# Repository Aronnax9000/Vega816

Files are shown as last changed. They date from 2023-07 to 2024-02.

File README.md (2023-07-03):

# Vega816 - Quad 65C816 Computer with Vector Pull rewrite

## Table of Contents

* [Functional Description](#functional-description)
* [CPU Buffer Board](#cpu-buffer-board)
* [DMA Control and Vector Pull Rewrite Shim](#dma-control-and-vector-pull-rewrite-shim)
    * [DMA Control Shim](#dma-control-shim)
    * [Vector Pull Rewrite Shim](#vector-pull-rewrite-shim)
    * [Offset of 7 triggers RESB interrupt handler for W65C816](#offset-of-7-triggers-resb-interrupt-handler-for-w65c816)
    * [Details of Vector Pull address rewriting](#details-of-vector-pull-address-rewriting)
    * [Effect of Vector Pull Rewrite in Emulation (65C02) Mode](#effect-of-vector-pull-rewrite-in-emulation-65c02-mode)
* [IRQ Dispatcher](#irq-dispatcher)
    * [IRQ Priority 7 to NMI Option](#irq-priority-7-to-nmi-option)
* [DMA Controller](#dma-controller)
    * [DMA Channels and Address Interleaving](#dma-channels-and-address-interleaving)
    * [How the DMA Controller routes requests](#how-the-dma-controller-routes-requests)
    * [DMA Request timing](#dma-request-timing)
* [Programmable Interrupt Controller (PIC)](#programmable-interrupt-controller-pic)
    * [2 Device PIC](#2-device-pic)
    * [Quad 2-Device PIC](#quad-2-device-pic)
* [16 MB Memory Decoder and Bus](#16-mb-memory-decoder-and-bus)
* [4 MB RAM + 32 K EEPROM Module](#4-mb-ram-32-k-eeprom-module)
* [Quad 64B I/O Bus](#quad-64b-i-o-bus)
* [Expansion Port to Single Device Ports](#expansion-port-to-single-device)
* [Single Device Port Breakouts](#single-device-port-breakouts)
* [Devices](#devices)
    * [W65C22 VIA Port](#w65c22-via-port)
    * [W65C51N ACIA (RS-232)](#w65c51n-acia-rs-232)
    * [8580/6581 SID](#8580-6581-sid)

* [VIA Port Devices](#via-port-devices)
    * [2x16 Character Display and front panel switches](#2x16-character-display-and-front-panel-switches)
    * [System Controller / SPI Controller](#system-controller-spi-controller)
    * [Ben Eater PS/2 Interface](#ben-eater-ps-2-interface)
    * [Commodore 64 CIA (VIA) #1](#commodore-64-cia-via-1)

## Functional Description
Vega 816 Block Diagram

The Vega816 is a modular architecture for implementing symmetrical multiprocessing (SMP) with the Western Design Center W65C816 Microprocessor (aka 65816). The project takes as its starting point the 65816 breakout board designed by Adrien Kohlbecker, documented at [the project's GitHub page](https://github.com/adrienkohlbecker/BB816) as well as [Adrien's YouTube series](https://www.youtube.com/playlist?list=PLdGm_pyUmoII9D16mzw-XsJjHKi3f1kqT).

Support is provided for up to four bus mastering devices (four CPUs, or three CPUs and a video card) accessing up to four DMA channels. Each DMA channel has full 24 bit addressing and therefore 16 MB of address space.

Through the use of software programmable banking registers, all four CPUs share access to all four 16 MB DMA channels, for a total of 64 MB of shared memory.

The architecture can be extended in a star pattern to form massively parallel networks, by connecting one DMA channel from one node as an input CPU channel on a higher-order node in the hierarchy.

## Modular Design

The design is implemented as a series of pluggable printed circuit modules, each introducing
one or two important layers of functionality to the basic system. Omitting a module should not interfere with the functioning of the remaining modules, except to omit the specific functionality it provides. Default settings in hardware and software exist to bypass any  undesired features. Interfaces between boards are designed as implementation neutral. For example, the CPU Buffer board takes only four inputs, each of which switches on one DMA channel. A DMA controller must be provided to make effective use of the board, but the choice of DMA controller is not forced, only the format of its required output.

## CPU Buffer Board

The CPU Buffer board provides two straight-wired connectors for the BB816 CPU breakout board, called "the CPU end", and buffers communications between the two of them and dual output connectors with the same pinout, called "the DMA end".

The extra straight wired connectors are included for ease of stacking the boards, both on the CPU end, and on the DMA end, in a multiplexed configuration, to implement shared memory multiprocessing. 

The circuit uses a 74AHCT245 octal bus transceiver for bi-directional communication for the 8 data lines, and seven 74HC541 octal buffers for the remaining signals provided by the BB816 CPU breakout board, including VPA and VDA. One of the buffers is allocated to CPU inputs (NMIB, IRQB, ABORTB, RDY_IN, etc), buffering signals from the DMA end. The remaining 74HC541s buffer lines from the CPU end onto the DMA end.

The bus transceiver and buffers' output enable lines are tied together and provided as an active low input called DMAB, so that a single signal suffices to turn communication on and off. A 1K pulldown resistor ensures that the board is active unless DMAB is raised high by external hardware.

CPU Buffer Board

## DMA Control and Vector Pull Rewrite Shim

If we assign each DMA channel its own address space, we can use address decoding in order to select which DMA channel is to be accessed by a particular CPU. In order to do that, we need to intercept the address lines from the CPU, pass decoding information to the DMA controller, and potentially rewrite the address being asserted by the CPU, before granting the CPU buffer access to the correct DMA channel.

The W65C816's VPB (Vector Pull) line also allows rewriting of the address asserted by the CPU when it is pulling an interrupt vector. It is convenient to provide hardware to intercept and rewrite the vector pull address as part of the same adapter.

Together, the DMA Control Shim and the Vector Pull Rewrite Shim provide facilities for DMA control and Vector Pull Rewrite to be performed by external hardware. 
CPU Shim

### DMA Control Shim

The DMA Control shim provides movable jumpers for each of the bits A16-A23. Any of the bits may be selected as DMA_REQ. Once the jumper has been set to select one of those lines, it is connected as the DMA_REQ output, and disconnected from output to the DMA end, and is in fact pulled low on the DMA end (10K resistor), in order to map the request into a lower part of the DMA channel's address space.

The jumper offers the user a choice of granularity of DMA channel address mapping, in multiple of 2 increments from 64K (single bank, the minimum granularity) to 4M maximum. This allows for the address space to be contiguous across all DMA channels, depending on installed memory sizes. Ordinarily, this jumper should be set to the size of the maximum address space serviced by the hardware on either DMA channel, e.g. the total installed memory on that channel, or half the total memory across the two channels.

### Vector Pull Rewrite Shim

The Vector Pull Rewrite shim allows the IRQ Dispatcher to alter the fetch address of the processor when it is fetching an IRQ vector. A three bit number between 0-7 is added to the least significant bits (but one) of the fetch address, A1-A3, with carry into A4.

The VPB line is brought active low by the 65C816 during the fetch of any interrupt vector, not just IRQ. However, the standard IRQ vector's address has a unique bit pattern which makes it easy to autodetect, so that the shim will only request a vector pull offset when fetching the IRQ vector, and not for any other kind of interrupt.

When VPB is active (low) and A1-A3 are all high, indicating that an interrupt vector is being fetched by the processor, the shim requests a vector pull offset from the IRQ Dispatcher by asserting VP_REQ (positive logic). Pulldown resistors keep the offset equal to zero when Y0-Y2 are not connected (no IRQ Dispatcher) or in a high impedance state. 

A 74HC283 adder is used to add an offset to A1-A4 equal to the three bit number provided as input to the shim from the IRQ Dispatcher, on pins Y0-Y2. This has the effect of altering the fetch of the IRQ vector at $FFEE to a fetch of a vector at one of the following eight addresses: 
```
$00FFEE IRQ 0 
$00FFF0 IRQ 1 
$00FFF2 IRQ 2 
$00FFF4 IRQ 3 
$00FFF6 IRQ 4 
$00FFF8 IRQ 5 
$00FFFA IRQ 6 
$00FFFC RESET 
```
Y0-Y2 are pulled low by 10K resistors, for cases in which no Vector Pull controller is connected. Bypass jumpers are also provided for A1-A4, in case the 74HC283 adder and supporting logic are not installed.

The connector for the external Vector Pull Rewrite controller provides the E signal from the CPU, so that the Vector Pull Rewrite controller can know which scheme of vector pull (W65C02, W65C816) is being used.

#### Exposure of NMI and IRQ

The Vector Pull Rewrite shim exposes both IRQ and NMI to the IRQ Dispatcher. 

If the IRQ Dispatcher is not installed, a jumper on the Quad 64 IO Bus (IRQ Dispatch Bypass) should be installed to route IRQs to the common IRQ signal on the CPU via the CPU Buffer's DMA Channel connector.

When the IRQ Dispatcher is installed, the dispatcher takes responsibility for issuing IRQ to the CPU, via the Vector Pull Rewrite shim.

The exposure of NMI allows a device to raise an  IRQs at a selected IRQ priority level (say, IRQ 7) and instead trigger NMI, as the Commodore 64 RESTORE key did. The assertion of NMI is left under the control of the IRQ Dispatcher.

In scenarios where the IRQ Dispatcher is not installed, a jumper on the Quad 64B IO Bus (NMI Dispatch Bypass) can be used to direct IRQA7, IRQB7, both, or neither, to NMI.

#### Offset of 7 triggers RESB interrupt handler for W65C816

Note that, when the 65816 is running in native mode, if an IRQ priority of 7 (0x111) is asserted on Y0-Y2, the vector offset will result in the RESET vector being pulled. Since no actual hardware reset has occurred, if the reset handler relies on a hardware reset having taken place, unpredictable state may occur. It is generally advised to avoid the use of IRQ priority 7 when the CPU is in native mode. Alternatively, IRQ priority 7 may be rerouted to NMI, either through the IRQ Dispatcher, or a jumper on the Quad 64B IO Bus.

#### Details of Vector Pull address rewriting
The W65C816 datasheet gives this table of interrupt vectors which lie between $00FFE4 and $00FFFC
```
Address Function Last Octet (binary)
$00FFE4 COP      0x1110 0100
$00FFE6 BRK      0x1110 0110
$00FFE8 ABORT    0x1110 1000
$00FFEA NMI      0x1110 1010
$00FFEE IRQ      0x1110 1110
$00FFFC RESET    0x1111 1100
```
The datasheet also specifies that when the 65C816 is addressing an interrupt vector, it pulls its VPB line low. This is to allow the system to override the fetched interrupt vector with any other. 

VPB is pulled low for any interrupt vector fetch, not just IRQ, but the present design purposefully limits Vector Pull rewriting to only those cases when IRQ is the vector being fetched.

Note that the last nybble of each of the standard interrupt vectors is unique, which aids in designing a hook for any one of them (the same is true for 6502 Emulation mode, see below). A test of these four bits suffices to uniquely identify the vector being pulled. In particular, both bytes of the two-byte IRQ vector ($FFEE and $FFEF) are the only two bytes in this table with $E or $F (0x1110, 0x1111) as the last nybble of address, i.e., A1-A3 high.

Note also the gap of 12 bytes between the IRQ vector and the RESET vector. Since each vector occupies two bytes, this gap provides sufficient space to specify six (6) additional vectors. 

```
$00FFE4 COP	
$00FFE6 BRK
$00FFE8 ABORT 
$00FFEA NMI 
$00FFEE IRQ 0 
$00FFF0 IRQ 1 
$00FFF2 IRQ 2 
$00FFF4 IRQ 3 
$00FFF6 IRQ 4 
$00FFF8 IRQ 5 
$00FFFA IRQ 6 
$00FFFC RESET 
```
If an offset 0-6 is added to A1-A3, (leaving A0 as found), then the vector fetched will be as shown above, going forward from IRQ0.

#### Effect of Vector Pull Rewrite in Emulation (65C02) Mode
The 6502's IRQ vector, like its 65816 counterpart, has 0x111x in the last nybble, so it is detected by the Vector Pull Rewrite Shim. 
```
$FFFA NMI
$FFFC RESB
$FFFE BRK/IRQ 
```
Unlike the 65816's IRQ vector, the 6502 IRQ vector occurs at the very top of its page, so additions of 1-7 to the bits may force A4 to overflow to 0 (no carry). In particular, $FFFE + $02 = $FFE0, etc. This means the augmented
IRQ vector map for the 6502 looks like this:

```
$FFE0 BRK/IRQ 1
$FFE2 BRK/IRQ 2
$FFE4 BRK/IRQ 3
$FFE6 BRK/IRQ 4
$FFE8 BRK/IRQ 5
$FFEA BRK/IRQ 6
$FFEC BRK/IRQ 7
...
$FFFA NMI
$FFFC RESB
$FFFE BRK/IRQ 0
```
## IRQ Dispatcher

Devices mapped within the physical address space of either DMA channel may raise interrupt requests against either CPU. For each CPU, an 8-to-3 priority encoders is used to prioritize eight different levels of IRQ, from 0-7, with lower values meaning higher priority.

The priority is encoded as a three bit offset and offered to the Vector Pull Rewrite shim, on pins Y0-Y2, where it is used to offset the fetch addresses of the CPU's next two-byte IRQ vector pull. 

IRQs received from DMA channel 0 and intended for CPU A or CPU B will be routed to those CPUs. 

For IRQs received from DMA channel 1, the situation is reversed: IRQs which DMA channel 1 intended for CPU A will be routed to CPU B, and vice versa. This crossover in routing means that the CPU target values in the system's PIC controllers always refer to the same physical CPU. I.e., CPU A is always target 0, and CPU B is always target 1, no matter on which DMA channel a PIC is installed. The crossover is reflected in the connector placement on the IRQ Dispatcher: no crossover cable is needed.

### IRQ Priority 7 to NMI Option

The combined IRQ signals are diode-NANDed together to drive IRQ on the CPU through the Vector Pull Rewrite shim. IRQ priorities 0-6 are NANDed together first, with priority 7 NANDed to the result unless jumper IRQA7 or IRQB7 are set to direct priority 7 to NMI to CPU A or CPU B.

Rerouting IRQ Priority 7 to NMI is offered elsewhere in the design, as a jumper on the Quad 64B IO Bus, for cases where no IRQ Dispatcher and/or Vector Pull Rewrite shim is installed. See the documentation on the Quad 64B IO Bus.

IRQ Dispatch

## DMA Controller

The DMA Controller is intended to control the multiplexing of one or two CPUs (called CPU A and CPU B) onto one or two communication channels (called DMA 0 and DMA 1). The two channels are cross-mapped in address space from the point of view of opposite processors, depending on a selected granularity. For example, if 64 KB (single bank) granularity is selected, when CPU A requests Bank 0, the DMA controller will connect it to DMA channel 0, whereas if CPU A requests Bank 1, the controller will connect it to DMA channel 1. The situation is reversed for CPU B. The controller will direct its requests for Bank 0 to DMA channel 1, and requests for Bank 1 to DMA channel 0.

This permits each CPU to have its Bank 0 lie within the address space of a separate physical DMA channel, so that accesses by each CPU to its own Bank 0 will not normally interfere with the opposite CPU's requests for its own Bank 0.

The effect for higher memory is that each CPU's odd numbered banks are the other CPU's even numbered banks, interleaved to the top of physical memory.

The granularity of the interleaving is specified by a jumper on the DMA Controller Shim, and provided to the DMA controller as the signal DMA_REQ. Additionally, the following CPU signals are utilized in implementing DMA:
```
RDY_IN
ABORTB
VA
```
Since the DMA controller will dispatch requests from up to two CPUs, CPU A and CPU B, the signals are distinguished within the controller with these designations:

Inputs
```
DMA_REQB_A DMA_REQB_A
RDY_IN_A  RDY_IN_B
ABORTB_A  ABORTB_B
VA_A      VA_B
```
Since the DMA channels are cross-mapped in address range between the two CPUs, so that each CPU's DMA 0 corresponds to the lower part of its address space with respect to DMA 1, the outputs are:
```
DMA_0_A  = DMA_1_B
DMA_1_A  = DMA_0_B
```
This cross mapping, which takes place in the connector wiring of the DMA Controller board, means that two identically configured units may be connected as CPU A or CPU B, provided that their DMA buffer modules are connected with the sense of DMA 0 and DMA 1 reversed.

The "home" channel for a CPU is the DMA channel containing that CPU's Bank Zero.

Here are the possible scenarios for DMA arbitration:

1. Both CPUs are asserting valid address, each against their own home DMA channels. CPU A is using DMA 0, and CPU B is using DMA 1.
2. Both CPUs are asserting valid address, against the opposite CPU's home DMA channel. CPU A is asserting against DMA 1, and CPU B is asserting against DMA 0.
3. Both CPUs are asserting valid address against the same DMA channel. CPU A is asserting against DMA 0, and so is CPU B.
4. Both CPUs are asserting valid address against the same DMA channel. CPU A is asserting against DMA 1, and so is CPU B.

The DMA controller monitors the VA (Valid Address) from one or two CPUs, as well as an additional input, DMA_REQB. If one CPU asserts DMA_REQB, the controller checks the VA line from the opposite CPU. If it is not active, the controller asserts DMA
DMA Controller

### DMA Channels and Address Interleaving

When no request granularity is set for a CPU on the DMA Control Shim, all DMA requests take place against DMA 0.

If only the primary granularity is set, DMA requests will take place against DMA 0 and DMA 2.
If only the secondary granularity is set, DMA requests will take place against DMA 0 and DMA 1.

If both granularities are set, DMA requests will take place against DMA 0-3. The maximum granularity for four channel DMA is 4 MB, with primary set at 8 MB and secondary set at 4MB. (0x1100 0000). In that case,

```
Requests for the range 
(0x00?? ????) go to DMA channel 0
(0x01?? ????) go to DMA channel 1
(0x10?? ????) go to DMA channel 2
(0x11?? ????) go to DMA channel 3
```

The DMA controller maps requests so that each CPU sees a different DMA channel as its channel 0, with subsequent channels in order. The next CPU's channel 0 is the present CPU's channel 1, and channel 0 for the next CPU after that is channel 2. The order wraps to form a closed ring.

```
           Requested           Physical
CPU   A    B      C      D
      0    1      2      3      DMA 0
      1    2      3      0      DMA 1
      2    3      0      1      DMA 2
      3    0      1      2      DMA 3
```

From the chart it can be seen that the channel that CPU A sees as DMA 0 is seen by CPU B as DMA channel 3, etc.

DMA request granularity may or may not match the largest installed address size.

Since the address bits used to select the DMA channels are suppressed in the address presented to the destination channel, if a CPU's request granularity is set to a smaller value than the installed memory size on any given DMA channel, then a range of that memory will not be accessible to that CPU.

CPU A has primary DMA on 1M, and secondary DMA set to 512K. 
CPU A issues requests against Banks 0 to 7.

What DMA channels are addressed?

```
0x000 Bank 0x000 0 on DMA 0
0x001 Bank 0x000 0 on DMA 1
0x010 Bank 0x000 0 on DMA 2
0x011 Bank 0x000 0 on DMA 3
0x100 Bank 0x100 4 on DMA 0
0x101 Bank 0x100 4 on DMA 1
0x110 Bank 0x100 4 on DMA 2
0x111 Bank 0x100 4 on DMA 3
```

### How the DMA Controller routes requests

Each request enters the DMA controller as a two bit code, representing the two address lines selected by jumper settings on the DMA Control Shim. These two bits are augmented with a third bit, a CPU Priority bit supplied for that CPU. The CPU Priority bit is active low, and pulled high. 

The three bit request is decoded into a one in eight choice, each representing a request for one of four DMA channels, with and without priority. The eight decoded request lines are then routed, together with the decoded request lines from the other CPUs, into priority encoders, one for each of the four DMA channels. The eight request lines entering each DMA channel's priority encoder are wired so that the four priority requests occur with highest priority, followed by the four no-priority request lines. Among the two sets of priority requests, Each DMA channel gives greatest priority to a particular CPU, followed by the others in ring order.

```
DMA Channel   Order
     0        ADCB                  
     1        BADC            
     2        CBAD
     3        DCBA            
```

When more than one CPU requests the same DMA channel, the losing CPU(s) must be informed, since they will not have access to the DMA channel for the duration of the current clock cycle. 

The W65C816 provides two mechanisms for this, the READY signal, and the ABORTB interrupt signal. The READY signal pauses the processor, if pulled low. Releasing the low condition, allowing READY to return high, will cause the CPU to resume processing on the rising edge of the next clock cycle.

Adrien Kohlbecker's BB816 CPU breakout provides the input to the READY signal as RDY_IN. This signal is that which is used by the DMA Controller to pause the CPU.

If the losing CPU is losing access to its Bank Zero channel (due to the winning CPU having priority bit active), the losing CPU is paused, by pulling RDY_IN low. 

Any other losing CPU is informed by pulling the losing CPU's ABORTB low, triggering the losing CPU's ABORT Interrupt handler. In most cases, the handler will simply return control to the interrupted process so that another attempt at access to the DMA channel can be made on the next clock cycle.

### DMA Request timing

CPU to DMA routing must be complete, with time to spare for the devices on the DMA channel to decode incoming address, before the routing is latched in on the falling edge of the clock. Now latched, the CPU to DMA channel routing persists through the remainder of the clock cycle, until unlatched at the rising edge of the clock at the beginning of the next cycle, so that arbitration may begin again.

## Quad 64B I/O Bus
The I/O bus board decodes a selected page (256 bytes) of address space for device I/O, together with a corresponding range in the the page immediately above it, for use by I/O devices.
3
Jumpers set the base I/O address space on any even-numbered page boundary in Bank Zero. The page of address space immediately above the base I/O page is reserved for configuring the programmable interrupt controller (PIC). For example, if the bus is set so that its base address is $0200, then page $0300 is reserved for use by the PIC.

The odd numbered page immediately above the base page is used by the programmable interrupt controller to store IRQ priority and CPU target information for use in forwarding interrupt requests issued by devices under PIC control.

In order to avoid the default page zero and stack areas at $0000 and $01000, it is advisable to avoid setting the I/O base address to page $00, leaving 63 possible pages between $0200-$7E00.

Four I/O expansion ports are provided, each spanning 64 bytes of the assigned I/O page. Each port is provided with a one-in-four chip select signal based on further decoding of the address, into 16 byte ranges areas. 
Standard connections are provided for adding a CS Decode module which can perform finer and/or coarser grained address decoding into 64, 32, and 8 byte I/O address ranges.

The 16 byte range chip select signals are raised high for both the I/O page within that 16 byte range, as well as for that range in the page immediately above it. E.g., if a device is mapped to $0210-$021F, then the chip select for that device is also active for the range $0310-$031F. This allows access to latches used to store programmable interrupt configuration, and potentially other metadata used in controlling the device.

The 16 IRQ output lines from each expansion port (8 priorities destined for one of up to two CPUs) are multiplexed via diode logic for dispatch by the IRQ Dispatch board.

Quad 64-byte Expansion Bus and IRQ Multiplexer

## Programmable Interrupt Controller (PIC)

### 2 Device PIC
The programmable interrupt controller accepts active low IRQ inputs from up to two sources. For each source, the PIC generates an interrupt signal at one of eight pre-selectable priorities (0-7), and directs the interrupt to a preselected one of two target CPUs. The PIC uses diode logic so that interrupts generated by multiple PICs may be placed on the same IRQ bus. 

The IRQ bus terminates at the IRQ Dispatcher, where 10K pull-up resistors ensure that lines on the IRQ bus are held high, unless pulled low by an interrupt signal originating at a PIC.

2 IRQ PIC

### Quad 2-Device PIC
A 64-byte expansion slot may include a programmable interrupt controller. The PIC subdivides the 64 byte address range into eight 8-byte device I/O spaces, two for each of the 16-byte address ranges decoded by the expansion bus controller and supplied to the PIC as chip select lines. 

Both IRQ priority (0-7) and CPU destination (CPU A or CPU B) can be programmed for each of up to eight devices, by writing to latches which shadow the device I/O space in the next higher page of address space. Four octal latches, at address offsets +$100, +$104, +$108 and +$10C offsets from the corresponding 16 byte I/O address ranges are provided. Each octal latch stores programmable interrupt information for up to two 8 byte devices: the low nybble for an eight byte device at offset +$00 from the base I/O address, and the high nybble for an eight byte device at offset $08 from the base I/O address. The low bit of the nybble determines the target CPU. The high three bits specify the priority from 0-7.
PIC (Programmable Interrupt Controller

## 16 MB Memory Decoder and Bus

16 MB Memory Decoder and Bus

## 4 MB RAM + 32 K EEPROM Module

4 MB RAM + 32 K EEPROM Module

## Expansion Port to Single Device

The 64-byte expansion slots provided by the Expansion Bus may be broken out into individual device I/O ports spanning 64, 32, 16, or 8 bytes of address space. The four 16-byte chip select lines are further decoded by the programmable interrupt controller down to two 8-byte chip select lines per 16 byte range.

These sample breakouts show a complete breakout of one port into 1x64, 2x32, 4x16 and 8x8 byte device ports. Also shown is a reduction of this most general breakout into a sample breakout capable of supporting 3 VIAs and 2 ACIAs.

Expansion Port to 64, 32, 16, 8 bit device ports

## Single Device Port Breakouts
A single 64, 32, or 16 byte device port may be further adapted to serve multiple devices of smaller address range. This approach introduces an extra address decoding delay compared with the above approach of adapting expansion bus directly.

Device Port External Breakouts

## Devices

### W65C22 VIA Port

This device presents the 20 outward facing lines of a VIA port, plus power and ground.

VIA Port

### W65C51N ACIA (RS-232)

This device supplies an RS-232 serial port.

ACIA Port

## VIA Port Devices

### 2x16 Character Display and front panel switches

2x16 Character Display

### System Controller / SPI Controller

The System Controller / SPI Controller is a VIA port device providing software control over system hardware.

Port A controls clock speed, CPU B RDY_IN and DMA priority control, and EEPROM banking on each of the DMA channels.

On system reset:

* CPU B is paused
* both CPUs are set to slow clock
* CPU B DMA Priority is turned off. CPU B will not be able to unilaterally deassert RDY_IN on CPU A for DMA operations.
* EEPROM on DMA 0 is set to read, with writes to the ROM area taking place against underlying RAM.
* EEPROM on DMA 1 is set to read, with writes to the ROM area taking place against underlying RAM.

A typical startup sequence would consist of these steps:

* CPU A copies EEPROM on DMA 0 to underlying RAM.
* CPU A copies EEPROM on DMA 1 to underlying RAM, or otherwise populates RAM underlying the DMA 1 ROM area.
* CPU A banks out EEPROMs for both read and write
* CPU A sets high clock speed for CPU A and CPU B
* If desired, CPU B is given DMA priority (e. g. for video processing).
* CPU A asserts RDY_IN on CPU B, permitting CPU B to start processing with CPU B's RESET vector.

Port B provides SPI communication, with SCK, MISO, MOSI lines, and three chip select lines, which in turn drive a 74AHC138 3-to-8 controller to select one of eight external SPI devices. PB6 and PB7 are reserved for pulse generation and pulse counting purposes (see W65C22 datasheet).

System and SPI Controller

### Ben Eater PS/2 Interface

Ben Eater PS/2 Interface

### Commodore 64 CIA (VIA) #1

Commodore 64 CIA (VIA) #1

### 8580/6581 SID

8580 or 6581 SID

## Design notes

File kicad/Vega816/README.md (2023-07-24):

# Vega816 - DMA Arbitration and VPB Rewrite for BB816 Breakout

The Vega816 is a SMP (Symmetrical Multiprocessing) architecture for Adrien Kohlbecker's 65816
Breakout Board, part of Adrien's astonishingly meticulous BB816 project. 
Hereinafter, unless otherwise specified, "CPU" refers to the W65C816S as wrapped 
in Adrien's W65C816 Breakout Board, or other device (e.g. GPU) made to expose relevant features of
the same interface. The current schematics reference BB816 Breakout Board Revision A.27.

The Vega816 allows up to four CPUs or other bus mastering devices shared access 
to up to four DMA channels, designated DMA0 to DMA3. Each DMA channel provides a
full 16 MB of address space. To ensure that each CPU has its own independent Bank Zero
at startup, each CPU has an independent physical DMA channel as its own "home" DMA0,
with the remaining channels numbered in circular fashion. 

As an independent feature, Vector Pull Rewrite is implemented, providing up to 8 separate
possible IRQ vectors, IRQB0-IRQB7. When an IRQ is asserted on one of the eight provided IRQ inputs,
a priority encoder calculates a three bit offset, and adds double this number to the address
being fetched by the CPU when an IRQ Vector Pull is detected (vectors occupy two bytes, accounting
for the doubled offset used to fetch both bytes). 

The Vector Pull Rewrite Feature works in either Emulation or Native mode.

## Implementation Details

Each CPU is mounted in a "CPU Shim", with identical input and output connectors each wired to 
the BB816 Breakout Board standard. The CPU Shim provides hardware hooks for connecting a DMA Controller,
and eight separate IRQ inputs used by the IRQ Priority Vector Pull Rewrite feature, which is 
also provided by the CPU Shim. 

Both the DMA Control section and the Vector Pull Rewrite section
may alter input and output between the CPU and the bus. For example, since the DMA process 
may result in a change to A23-A22, the BANK0B line is recalculated, so that the value on the bus
reflects whether Bank Zero is being requested on the destination DMA channel.

The CPU Shim is mounted on the CPU Buffer Board, which buffers access between the CPU and one out of 
up to four physical DMA channels. Each DMA channel on the buffer board replicates the full 
BB816 Breakout Board interface. Any hardware built to accept a BB816 Breakout Board 
as its CPU can be attached to a DMA channel without modification. 

The CPU Buffer takes a 1-of-4 input which switches on one of the four physical DMA channel
buffers. 

When not enabled, each DMA channel is in a high impedance state. This allows the buffer 
boards to be "stacked": DMA channels from separate boards may be physically connected 
together so that multiple CPUs share multiple DMA channels. If very long/tall pin headers
are installed, the boards may be physically stacked one atop another. 

When DMA requests are not enabled for a particular CPU, it will always request DMA0. 
When DMA requests are enabled for a particular CPU, the lines A23 and A22 are
decoded as the requested DMA channel and passed to the DMA Controller, along with a priority bit
setting.  

A four channel DMA Controller accepts requests from up to four CPUs, and uses priority decoding
logic to assign CPUs to DMA channels on each clock cycle. A CPU which does not
"win" access to its requested DMA channel is "paused" for one cycle. A pulse is
applied to that CPU's READY_IN, causing it to pause until the falling edge of the next
clock cycle.

Under ordinary circumstances, a CPU always wins priority access to the DMA 
channel that it has designated DMA0. If another CPU (GPU) needs access to
another CPU's DMA0, it will be paused, unless it also has asserted a "Priority Bit"
to the DMA Controller. In that case, the CPU whose home DMA0 channel has been
requested by the visiting CPU will be paused, instead, and the visiting
CPU will be granted access. This feature supports real time applications 
such as VIC-II and World's Worst Video Card style DMA.

Each CPU is mounted on a CPU Shim, consisting of a DMA Shim and Vector Pull Rewrite Shim.

The DMA Control Shim monitors CPU address lines and, when the CPU is in Native mode,
issues DMA requests to the DMA Controller. The DMA Controller performs bus arbitration among
the installed CPUs. If a CPU wins access to a DMA channel for a given clock cycle,
its DMA Control Shim receives the go-ahead from the DMA Controller, and switches on the
correct channel on the CPU's CPU Buffer. Otherwise, the DMA Control Shim pauses its
CPU, by asserting RDY_IN low.

The Vector Pull Rewrite Shim allows eight levels of IRQ priority from 0-7. Priority 7 may be 
rerouted to perform NMI instead. When one of the IRQ inputs not designated for NMI
is pulled low, the VPB Rewrite Shim pulls IRQ low on the CPU, and
monitors VPB and A0-A8 to detect when the interrupt vector is pulled by the CPU in response.
The VPB Rewrite Shim then modifies the fetched vector's address by adding an even number
offset between 0 and 14 to the vector fetch address. The number is calculated as twice the
highest IRQ Priority of the current asserted IRQs.
    
## Functional Description
Vega 816 Block Diagram

The Vega816 is a modular architecture for implementing symmetrical multiprocessing (SMP) with the Western Design Center W65C816 Microprocessor (aka 65816). The project takes as its starting point the 65816 breakout board designed by Adrien Kohlbecker, documented at [the project's GitHub page](https://github.com/adrienkohlbecker/BB816) as well as [Adrien's YouTube series](https://www.youtube.com/playlist?list=PLdGm_pyUmoII9D16mzw-XsJjHKi3f1kqT).

Support is provided for up to four bus mastering devices (four CPUs, or three CPUs and a video card) accessing up to four DMA channels. Each DMA channel has full 24 bit addressing and therefore 16 MB of address space.

Through the use of software programmable banking registers, all four CPUs share access to all four 16 MB DMA channels, for a total of 64 MB of shared memory.

The architecture can be extended in a star pattern to form massively parallel networks, by connecting one DMA channel from one node as an input CPU channel on a higher-order node in the hierarchy.

The DMA Control shim provides movable jumpers for each of the bits A16-A23. Any of the bits may be selected as DMA_REQ. Once the jumper has been set to select one of those lines, it is connected as the DMA_REQ output, and disconnected from output to the DMA end, and is in fact pulled low on the DMA end (10K resistor), in order to map the request into a lower part of the DMA channel's address space.

The jumper offers the user a choice of granularity of DMA channel address mapping, in multiple of 2 increments from 64K (single bank, the minimum granularity) to 4M maximum. This allows for the address space to be contiguous across all DMA channels, depending on installed memory sizes. Ordinarily, this jumper should be set to the size of the maximum address space serviced by the hardware on either DMA channel, e.g. the total installed memory on that channel, or half the total memory across the two channels.

# Vector Pull Rewrite 

The Vector Pull Rewrite feature allows the IRQ Dispatcher to alter the fetch address of the processor when it is fetching an IRQ vector. A three bit number between 0-7 is added to the least significant bits (but one) of the fetch address, A1-A3, with carry into A4.

The VPB line is brought active low by the 65C816 during the fetch of any interrupt vector, not just IRQ. However, the standard IRQ vector's address has a unique bit pattern which makes it easy to autodetect, so that the shim will only request a vector pull offset when fetching the IRQ vector, and not for any other kind of interrupt.

When VPB is active (low) and A1-A3 are all high, indicating that an interrupt vector is being fetched by the processor, the shim requests a vector pull offset from the IRQ Dispatcher by asserting VP_REQ (positive logic). Pulldown resistors keep the offset equal to zero when Y0-Y2 are not connected (no IRQ Dispatcher) or in a high impedance state. 

A 74HC283 adder is used to add an offset to A1-A4 equal to the three bit number provided as input to the shim from the IRQ Dispatcher, on pins Y0-Y2. This has the effect of altering the fetch of the IRQ vector at $FFEE to a fetch of a vector at one of the following eight addresses: 
```
$00FFEE IRQ 0 
$00FFF0 IRQ 1 
$00FFF2 IRQ 2 
$00FFF4 IRQ 3 
$00FFF6 IRQ 4 
$00FFF8 IRQ 5 
$00FFFA IRQ 6 
$00FFFC RESET 
```
Y0-Y2 are pulled low by 10K resistors, for cases in which no Vector Pull controller is connected. Bypass jumpers are also provided for A1-A4, in case the 74HC283 adder and supporting logic are not installed.

The connector for the external Vector Pull Rewrite controller provides the E signal from the CPU, so that the Vector Pull Rewrite controller can know which scheme of vector pull (W65C02, W65C816) is being used.

#### Exposure of NMI and IRQ

The Vector Pull Rewrite shim exposes both IRQ and NMI to the IRQ Dispatcher. 

If the IRQ Dispatcher is not installed, a jumper on the Quad 64 IO Bus (IRQ Dispatch Bypass) should be installed to route IRQs to the common IRQ signal on the CPU via the CPU Buffer's DMA Channel connector.

When the IRQ Dispatcher is installed, the dispatcher takes responsibility for issuing IRQ to the CPU, via the Vector Pull Rewrite shim.

The exposure of NMI allows a device to raise an  IRQs at a selected IRQ priority level (say, IRQ 7) and instead trigger NMI, as the Commodore 64 RESTORE key did. The assertion of NMI is left under the control of the IRQ Dispatcher.

In scenarios where the IRQ Dispatcher is not installed, a jumper on the Quad 64B IO Bus (NMI Dispatch Bypass) can be used to direct IRQA7, IRQB7, both, or neither, to NMI.

#### Offset of 7 triggers RESB interrupt handler for W65C816

Note that, when the 65816 is running in native mode, if an IRQ priority of 7 (0x111) is asserted on Y0-Y2, the vector offset will result in the RESET vector being pulled. Since no actual hardware reset has occurred, if the reset handler relies on a hardware reset having taken place, unpredictable state may occur. It is generally advised to avoid the use of IRQ priority 7 when the CPU is in native mode. Alternatively, IRQ priority 7 may be rerouted to NMI, either through the IRQ Dispatcher, or a jumper on the Quad 64B IO Bus.

#### Details of Vector Pull address rewriting
The W65C816 datasheet gives this table of interrupt vectors which lie between $00FFE4 and $00FFFC
```
Address Function Last Octet (binary)
$00FFE4 COP      0x1110 0100
$00FFE6 BRK      0x1110 0110
$00FFE8 ABORT    0x1110 1000
$00FFEA NMI      0x1110 1010
$00FFEE IRQ      0x1110 1110
$00FFFC RESET    0x1111 1100
```
The datasheet also specifies that when the 65C816 is addressing an interrupt vector, it pulls its VPB line low. This is to allow the system to override the fetched interrupt vector with any other. 

VPB is pulled low for any interrupt vector fetch, not just IRQ, but the present design purposefully limits Vector Pull rewriting to only those cases when IRQ is the vector being fetched.

Note that the last nybble of each of the standard interrupt vectors is unique, which aids in designing a hook for any one of them (the same is true for 6502 Emulation mode, see below). A test of these four bits suffices to uniquely identify the vector being pulled. In particular, both bytes of the two-byte IRQ vector ($FFEE and $FFEF) are the only two bytes in this table with $E or $F (0x1110, 0x1111) as the last nybble of address, i.e., A1-A3 high.

Note also the gap of 12 bytes between the IRQ vector and the RESET vector. Since each vector occupies two bytes, this gap provides sufficient space to specify six (6) additional vectors. 

```
$00FFE4 COP	
$00FFE6 BRK
$00FFE8 ABORT 
$00FFEA NMI 
$00FFEE IRQ 0 
$00FFF0 IRQ 1 
$00FFF2 IRQ 2 
$00FFF4 IRQ 3 
$00FFF6 IRQ 4 
$00FFF8 IRQ 5 
$00FFFA IRQ 6 
$00FFFC RESET 
```
If an offset 0-6 is added to A1-A3, (leaving A0 as found), then the vector fetched will be as shown above, going forward from IRQ0.

#### Effect of Vector Pull Rewrite in Emulation (65C02) Mode
The 6502's IRQ vector, like its 65816 counterpart, has 0x111x in the last nybble, so it is detected by the Vector Pull Rewrite Shim. 
```
$FFFA NMI
$FFFC RESB
$FFFE BRK/IRQ 
```
Unlike the 65816's IRQ vector, the 6502 IRQ vector occurs at the very top of its page, so additions of 1-7 to the bits may force A4 to overflow to 0 (no carry). In particular, $FFFE + $02 = $FFE0, etc. This means the augmented
IRQ vector map for the 6502 looks like this:

```
$FFE0 BRK/IRQ 1
$FFE2 BRK/IRQ 2
$FFE4 BRK/IRQ 3
$FFE6 BRK/IRQ 4
$FFE8 BRK/IRQ 5
$FFEA BRK/IRQ 6
$FFEC BRK/IRQ 7
...
$FFFA NMI
$FFFC RESB
$FFFE BRK/IRQ 0
```
## IRQ Dispatcher

Devices mapped within the physical address space of either DMA channel may raise interrupt requests against either CPU. For each CPU, an 8-to-3 priority encoders is used to prioritize eight different levels of IRQ, from 0-7, with lower values meaning higher priority.

The priority is encoded as a three bit offset, and this value is added to A1-A3, effectively adding double the offset to the address to be pulled. (Double, since each vector occupies two consecutive bytes)

IRQs received from DMA channel 0 and intended for CPU A or CPU B will be routed to those CPUs. 

For IRQs received from DMA channel 1, the situation is reversed: IRQs which DMA channel 1 intended for CPU A will be routed to CPU B, and vice versa. This crossover in routing means that the CPU target values in the system's PIC controllers always refer to the same physical CPU. I.e., CPU A is always target 0, and CPU B is always target 1, no matter on which DMA channel a PIC is installed. The crossover is reflected in the connector placement on the IRQ Dispatcher: no crossover cable is needed.

### IRQ Priority 7 to NMI Option

A jumper on the CPU Shim allows IRQ7B to trigger NMIB instead of participating in Vector Pull Rewrite.
This is intended to support devices such as the RESTORE key on the C64, which expects to be able to
assert NMIB.

# DMA Controller

The DMA Controller is intended to control the multiplexing of one or two CPUs (called CPU A and CPU B) onto one or two communication channels (called DMA 0 and DMA 1). The two channels are cross-mapped in address space from the point of view of opposite processors, depending on a selected granularity. For example, if 64 KB (single bank) granularity is selected, when CPU A requests Bank 0, the DMA controller will connect it to DMA channel 0, whereas if CPU A requests Bank 1, the controller will connect it to DMA channel 1. The situation is reversed for CPU B. The controller will direct its requests for Bank 0 to DMA channel 1, and requests for Bank 1 to DMA channel 0.

This permits each CPU to have its Bank 0 lie within the address space of a separate physical DMA channel, so that accesses by each CPU to its own Bank 0 will not normally interfere with the opposite CPU's requests for its own Bank 0.

The effect for higher memory is that each CPU's odd numbered banks are the other CPU's even numbered banks, interleaved to the top of physical memory.

The granularity of the interleaving is specified by a jumper on the DMA Controller Shim, and provided to the DMA controller as the signal DMA_REQ. Additionally, the following CPU signals are utilized in implementing DMA:
```
RDY_IN
ABORTB
VA
```
Since the DMA controller will dispatch requests from up to two CPUs, CPU A and CPU B, the signals are distinguished within the controller with these designations:

Inputs
```
DMA_REQB_A DMA_REQB_A
RDY_IN_A  RDY_IN_B
ABORTB_A  ABORTB_B
VA_A      VA_B
```
Since the DMA channels are cross-mapped in address range between the two CPUs, so that each CPU's DMA 0 corresponds to the lower part of its address space with respect to DMA 1, the outputs are:
```
DMA_0_A  = DMA_1_B
DMA_1_A  = DMA_0_B
```
This cross mapping, which takes place in the connector wiring of the DMA Controller board, means that two identically configured units may be connected as CPU A or CPU B, provided that their DMA buffer modules are connected with the sense of DMA 0 and DMA 1 reversed.

The "home" channel for a CPU is the DMA channel containing that CPU's Bank Zero.

Here are the possible scenarios for DMA arbitration:

1. Both CPUs are asserting valid address, each against their own home DMA channels. CPU A is using DMA 0, and CPU B is using DMA 1.
2. Both CPUs are asserting valid address, against the opposite CPU's home DMA channel. CPU A is asserting against DMA 1, and CPU B is asserting against DMA 0.
3. Both CPUs are asserting valid address against the same DMA channel. CPU A is asserting against DMA 0, and so is CPU B.
4. Both CPUs are asserting valid address against the same DMA channel. CPU A is asserting against DMA 1, and so is CPU B.

The DMA controller monitors the VA (Valid Address) from one or two CPUs, as well as an additional input, DMA_REQB. If one CPU asserts DMA_REQB, the controller checks the VA line from the opposite CPU. If it is not active, the controller asserts DMA
DMA Controller

### DMA Channels and Address Interleaving

When no request granularity is set for a CPU on the DMA Control Shim, all DMA requests take place against DMA 0.

If only the primary granularity is set, DMA requests will take place against DMA 0 and DMA 2.
If only the secondary granularity is set, DMA requests will take place against DMA 0 and DMA 1.

If both granularities are set, DMA requests will take place against DMA 0-3. The maximum granularity for four channel DMA is 4 MB, with primary set at 8 MB and secondary set at 4MB. (0x1100 0000). In that case,

```
Requests for the range 
(0x00?? ????) go to DMA channel 0
(0x01?? ????) go to DMA channel 1
(0x10?? ????) go to DMA channel 2
(0x11?? ????) go to DMA channel 3
```

The DMA controller maps requests so that each CPU sees a different DMA channel as its channel 0, with subsequent channels in order. The next CPU's channel 0 is the present CPU's channel 1, and channel 0 for the next CPU after that is channel 2. The order wraps to form a closed ring.

```
           Requested           Physical
CPU   A    B      C      D
      0    1      2      3      DMA 0
      1    2      3      0      DMA 1
      2    3      0      1      DMA 2
      3    0      1      2      DMA 3
```

From the chart it can be seen that the channel that CPU A sees as DMA 0 is seen by CPU B as DMA channel 3, etc.

DMA request granularity may or may not match the largest installed address size.

Since the address bits used to select the DMA channels are suppressed in the address presented to the destination channel, if a CPU's request granularity is set to a smaller value than the installed memory size on any given DMA channel, then a range of that memory will not be accessible to that CPU.

CPU A has primary DMA on 1M, and secondary DMA set to 512K. 
CPU A issues requests against Banks 0 to 7.

What DMA channels are addressed?

```
0x000 Bank 0x000 0 on DMA 0
0x001 Bank 0x000 0 on DMA 1
0x010 Bank 0x000 0 on DMA 2
0x011 Bank 0x000 0 on DMA 3
0x100 Bank 0x100 4 on DMA 0
0x101 Bank 0x100 4 on DMA 1
0x110 Bank 0x100 4 on DMA 2
0x111 Bank 0x100 4 on DMA 3
```

### How the DMA Controller routes requests

Each request enters the DMA controller as a two bit code, representing the two address lines selected by jumper settings on the DMA Control Shim. These two bits are augmented with a third bit, a CPU Priority bit supplied for that CPU. The CPU Priority bit is active low, and pulled high. 

The three bit request is decoded into a one in eight choice, each representing a request for one of four DMA channels, with and without priority. The eight decoded request lines are then routed, together with the decoded request lines from the other CPUs, into priority encoders, one for each of the four DMA channels. The eight request lines entering each DMA channel's priority encoder are wired so that the four priority requests occur with highest priority, followed by the four no-priority request lines. Among the two sets of priority requests, Each DMA channel gives greatest priority to a particular CPU, followed by the others in ring order.

```
DMA Channel   Order
     0        ADCB                  
     1        BADC            
     2        CBAD
     3        DCBA            
```

When more than one CPU requests the same DMA channel, the losing CPU(s) must be informed, since they will not have access to the DMA channel for the duration of the current clock cycle. 

The W65C816 provides two mechanisms for this, the READY signal, and the ABORTB interrupt signal. The READY signal pauses the processor, if pulled low. Releasing the low condition, allowing READY to return high, will cause the CPU to resume processing on the rising edge of the next clock cycle.

Adrien Kohlbecker's BB816 CPU breakout provides the input to the READY signal as RDY_IN. This signal is that which is used by the DMA Controller to pause the CPU.

If the losing CPU is losing access to its Bank Zero channel (due to the winning CPU having priority bit active), the losing CPU is paused, by pulling RDY_IN low. 

Any other losing CPU is informed by pulling the losing CPU's ABORTB low, triggering the losing CPU's ABORT Interrupt handler. In most cases, the handler will simply return control to the interrupted process so that another attempt at access to the DMA channel can be made on the next clock cycle.

### DMA Request timing

CPU to DMA routing must be complete, with time to spare for the devices on the DMA channel to decode incoming address, before the routing is latched in on the falling edge of the clock. Now latched, the CPU to DMA channel routing persists through the remainder of the clock cycle, until unlatched at the rising edge of the clock at the beginning of the next cycle, so that arbitration may begin again.

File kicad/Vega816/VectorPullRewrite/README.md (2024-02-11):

## Vector Pull Rewrite 

The W65C816 datasheet gives this table of interrupt vectors which lie between $00FFE4 and $00FFFC, when the processor is in Native mode:

```
Native Mode (65C816) Interrupt Vector Table (datasheet)

$FFE4 COP      
$FFE6 BRK      
$FFE8 ABORT    
$FFEA NMI      
$FFEE IRQ      
$FFFC RESET    
```
Note that in native mode, between the addresses for the IRQ and RESET vectors, there are six vectors' (twelve bytes) worth of unused addresses, $FFF0-$FFFB. 
This strongly suggests the possibility of using the vector pull line to up to add additional six different IRQ vectors, by rewriting the address of the vector to be pulled. The feature described here alters the addresses fetched by the CPU when it fetches an IRQ vector. The result is the following expanded table of interrupts.

```
W65C816 Native Interrupt Vector Table (after rewrite)

$FFE4 COP      
$FFE6 BRK      
$FFE8 ABORT    
$FFEA NMI      
$FFEE IRQ 0 
$FFF0 IRQ 1 
$FFF2 IRQ 2 
$FFF4 IRQ 3 
$FFF6 IRQ 4 
$FFF8 IRQ 5 
$FFFA IRQ 6 
$FFFC RESET

```

## Theory of operation
The circuit has 7 input lines, active low, designated IRQ0B through IRQ6B. While one or more of them is asserted low, IRQ on the processor is pulled low. A priorty encoder encodes the number of the lowest-numbered active input. Twice this number is offered to a 4-bit adder added to the low order byte of the vector pull.
When
The circuit detects vector pulls to the IRQ vector, $FFEE, and rewrites the low order byte of the fetch.

When E is low (native mode), and VPB goes low (active), the CPU is in native mode and asserting the address of an interrupt vector on the address lines. The current memory access fetches the low byte of the vector, and the next memory access fetches the high byte. Since the 

and the high three bits of the low order nybble of the address are examined. 

A three bit number between 0-7 is added to the least significant bits (but one) of the fetch address, A1-A3, with carry into A4.

The VPB line is brought active low by the 65C816 during the fetch of any interrupt vector, not just IRQ. However, the standard IRQ vector's address has a unique bit pattern which makes it easy to detect, so that an offset when fetching an IRQ vector, and not for any other kind of interrupt.

When VPB is active (low) and A1-A3 are all high, indicating that an interrupt vector is being fetched by the processor, the shim requests a vector pull offset from the IRQ Dispatcher by asserting VP_REQ (positive logic). Pulldown resistors keep the offset equal to zero when Y0-Y2 are not connected (no IRQ Dispatcher) or in a high impedance state. 

A 74HC283 adder is used to add an offset to A1-A4 equal to the three bit number provided as input to the shim from the IRQ Dispatcher, on pins Y0-Y2. This has the effect of altering the fetch of the IRQ vector at $FFEE to a fetch of a vector at one of the following eight addresses: 

Y0-Y2 are pulled low by 10K resistors, for cases in which no Vector Pull controller is connected. Bypass jumpers are also provided for A1-A4, in case the 74HC283 adder and supporting logic are not installed.

#### Details of Vector Pull address rewriting

The datasheet also specifies that when the 65C816 is addressing an interrupt vector, it pulls its VPB line low. This is to allow the system to override the fetched interrupt vector with any other. 

VPB is pulled low for any interrupt vector fetch, not just IRQ, but the present design purposefully limits Vector Pull rewriting to only those cases when IRQ is the vector being fetched.

Note that the last nybble of each of the standard interrupt vectors is unique, which aids in designing a hook for any one of them (the same is true for 6502 Emulation mode, see below). A test of these four bits suffices to uniquely identify the vector being pulled. In particular, both bytes of the two-byte IRQ vector ($FFEE and $FFEF) are the only two bytes in this table with $E or $F (0x1110, 0x1111) as the last nybble of address, i.e., A1-A3 high.

Note also the gap of 12 bytes between the IRQ vector and the RESET vector. Since each vector occupies two bytes, this gap provides sufficient space to specify six (6) additional vectors. 

```
Native Mode Interrupt Vector Table (with IRQ0-7)

$00FFE4 COP	
$00FFE6 BRK
$00FFE8 ABORT 
$00FFEA NMI 
$00FFEE IRQ 0 
$00FFF0 IRQ 1 
$00FFF2 IRQ 2 
$00FFF4 IRQ 3 
$00FFF6 IRQ 4 
$00FFF8 IRQ 5 
$00FFFA IRQ 6 
$00FFFC RESET 
```

While an IRQ vector is being pulled, if an offset [0..7]*2 is added to the address asserted on the bus, then the vector fetched will be as shown above, going forward from IRQ0.

## IRQ Priority Dispatch

The Vector Pull Rewrite portion of the CPU shim exposes eight inputs, active low, as IRQ0B-IRQ7B. Devices connected to any DMA channel may direct an IRQ to the CPU, by asserting one of these inputs. 

An 8-to-3 priority encoder is used to prioritize eight different levels of IRQ, from 0-7 (lowest value wins).

The priority is encoded as a three bit offset, and this value is added to A1-A3, effectively adding double the offset to the address to be pulled. (Double, since each vector occupies two consecutive bytes)

## Native Mode: IRQ7 triggers RESET interrupt handler 

Note that, when the 65816 is running in native mode, if an IRQ priority of 7 (0x111) is asserted on Y0-Y2, the vector offset will result in the RESET vector being pulled. Since no actual hardware reset has occurred, if the reset handler relies on a hardware reset having taken place, unpredictable state may occur. It is generally advised to avoid the use of IRQ priority 7 when the CPU is in native mode. Alternatively, IRQ priority 7 may be rerouted to NMI.

## IRQ Priority 7 to NMI Option

A jumper on the CPU Shim allows IRQ7 to trigger an NMI instead of participating in Vector Pull Rewrite.
This is intended to support devices such as the RESTORE key on the C64, which expects to be able to
assert NMIB. Another motivation is to provide a useful alternative to the default effect of asserting
IRQ7 within the rewrite scheme, which is to force the pull of the RESET vector.

## Effect of Vector Pull Rewrite in Emulation (65C02) Mode
The 6502's IRQ vector, like its 65816 counterpart, has 0x111x in the last nybble, so it is detected by the Vector Pull Rewrite Shim. 

```
Emulation Mode Interrupt Vector Table  (datasheet)

$FFFA NMI
$FFFC RESB
$FFFE BRK/IRQ 
```

Unlike the 65816's IRQ vector, the 6502 IRQ vector occurs at the very top of its page, so additions of 1-7 to the bits may force A4 to overflow to 0 (no carry). In particular, $FFFE + $02 = $FFE0, etc. This means the augmented
IRQ vector map for the 6502 looks like this:

```
Emulation Mode Interrupt Vector Table (with IRQ0-7)

$FFE0 BRK/IRQ 1
$FFE2 BRK/IRQ 2
$FFE4 BRK/IRQ 3
$FFE6 BRK/IRQ 4
$FFE8 BRK/IRQ 5
$FFEA BRK/IRQ 6
$FFEC BRK/IRQ 7
...
$FFFA NMI
$FFFC RESB
$FFFE BRK/IRQ 0
```

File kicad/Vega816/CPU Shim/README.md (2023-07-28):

# CPU Shim

## DMA control (Native Mode Only)

DMA channel selection is based on address bits not available in Emulation mode. Accordingly, the DMA
control portion of the CPU shim operates only when the CPU has indicated that 
it is in native mode (E bit low).

The DMA control portion of the CPU shim satisfies the requirements listed below. The design is intended 
to be agnostic with regard to the design of the external DMA controller, beyond the choice of interpreting
A22-A23 as the requested DMA channel (when requests are enabled).

1. Issue requests to the DMA Controller (if installed), for a particular DMA channel,
based on A23-A22, and configuration settings (DMA enable/disable, optional priority bit).
2. Receive response from the DMA Controller indicating which DMA channel (if any) has been granted for access. 
3. Optionally rewrite address bits A23-A22 to be asserted on the bus, 
to allow full access to each DMA channel's 16MB address space, based on configuration settings for each of DMA1-3.
4. If the DMA Controller grants access to the requested DMA channel, inform the CPU Buffer which channel to access. 
5. If the DMA Controller does not grant access to the requested DMA channel, 
pause the CPU for one clock cycle, using the RDY_IN signal.
6. Expose configuration settings (DMA Request Enable, address rewrite, priority bit) to outside hardware, 
e.g. a software driven latch, to allow software control of DMA configuration.

The DMA control portion of the CPU shim features bypass jumpers which may be used to bypass the address rewrite functions,
when no extenal DMA Controller is supplied.

## Vector Pull Rewrite 

The CPU shim passes incoming IRQs from the bus to the CPU. However, it also provides eight independent IRQ inputs, IRQ0B to IRQ7B,
connected to a priority-based Vector Pull Rewrite feature.

The Vector Pull Rewrite feature alters the fetch address of the CPU when it fetches an IRQ vector, 
by adding an offset to the fetch address equal to twice the winning IRQ's order number:

```
Native Mode Offsets

IRQ
#
0    $00FFEE IRQ 0 
1    $00FFF0 IRQ 1 
2    $00FFF2 IRQ 2 
3    $00FFF4 IRQ 3 
4    $00FFF6 IRQ 4 
5    $00FFF8 IRQ 5 
6    $00FFFA IRQ 6 
7    $00FFFC RESET 
```

0 for IRQ0
A three bit number between 0-7 is added to the least significant bits (but one) of the fetch address, A1-A3, with carry into A4.

The VPB line is brought active low by the 65C816 during the fetch of any interrupt vector, not just IRQ. However, the standard IRQ vector's address has a unique bit pattern which makes it easy to detect, so that an offset when fetching an IRQ vector, and not for any other kind of interrupt.

When VPB is active (low) and A1-A3 are all high, indicating that an interrupt vector is being fetched by the processor, the shim requests a vector pull offset from the IRQ Dispatcher by asserting VP_REQ (positive logic). Pulldown resistors keep the offset equal to zero when Y0-Y2 are not connected (no IRQ Dispatcher) or in a high impedance state. 

A 74HC283 adder is used to add an offset to A1-A4 equal to the three bit number provided as input to the shim from the IRQ Dispatcher, on pins Y0-Y2. This has the effect of altering the fetch of the IRQ vector at $FFEE to a fetch of a vector at one of the following eight addresses: 

Y0-Y2 are pulled low by 10K resistors, for cases in which no Vector Pull controller is connected. Bypass jumpers are also provided for A1-A4, in case the 74HC283 adder and supporting logic are not installed.

#### Details of Vector Pull address rewriting
The W65C816 datasheet gives this table of interrupt vectors which lie between $00FFE4 and $00FFFC, when the processor is in Native mode:

```
Native Mode Interrupt Vector Table (datasheet)

Address Function Last Octet (binary)
$00FFE4 COP      0x1110 0100
$00FFE6 BRK      0x1110 0110
$00FFE8 ABORT    0x1110 1000
$00FFEA NMI      0x1110 1010
$00FFEE IRQ      0x1110 1110
$00FFFC RESET    0x1111 1100
```

The datasheet also specifies that when the 65C816 is addressing an interrupt vector, it pulls its VPB line low. This is to allow the system to override the fetched interrupt vector with any other. 

VPB is pulled low for any interrupt vector fetch, not just IRQ, but the present design purposefully limits Vector Pull rewriting to only those cases when IRQ is the vector being fetched.

Note that the last nybble of each of the standard interrupt vectors is unique, which aids in designing a hook for any one of them (the same is true for 6502 Emulation mode, see below). A test of these four bits suffices to uniquely identify the vector being pulled. In particular, both bytes of the two-byte IRQ vector ($FFEE and $FFEF) are the only two bytes in this table with $E or $F (0x1110, 0x1111) as the last nybble of address, i.e., A1-A3 high.

Note also the gap of 12 bytes between the IRQ vector and the RESET vector. Since each vector occupies two bytes, this gap provides sufficient space to specify six (6) additional vectors. 

```
Native Mode Interrupt Vector Table (with IRQ0-7)

$00FFE4 COP	
$00FFE6 BRK
$00FFE8 ABORT 
$00FFEA NMI 
$00FFEE IRQ 0 
$00FFF0 IRQ 1 
$00FFF2 IRQ 2 
$00FFF4 IRQ 3 
$00FFF6 IRQ 4 
$00FFF8 IRQ 5 
$00FFFA IRQ 6 
$00FFFC RESET 
```

While an IRQ vector is being pulled, if an offset [0..7]*2 is added to the address asserted on the bus, then the vector fetched will be as shown above, going forward from IRQ0.

## IRQ Priority Dispatch

The Vector Pull Rewrite portion of the CPU shim exposes eight inputs, active low, as IRQ0B-IRQ7B. Devices connected to any DMA channel may direct an IRQ to the CPU, by asserting one of these inputs. 

An 8-to-3 priority encoder is used to prioritize eight different levels of IRQ, from 0-7 (lowest value wins).

The priority is encoded as a three bit offset, and this value is added to A1-A3, effectively adding double the offset to the address to be pulled. (Double, since each vector occupies two consecutive bytes)

## Native Mode: IRQ7 triggers RESET interrupt handler 

Note that, when the 65816 is running in native mode, if an IRQ priority of 7 (0x111) is asserted on Y0-Y2, the vector offset will result in the RESET vector being pulled. Since no actual hardware reset has occurred, if the reset handler relies on a hardware reset having taken place, unpredictable state may occur. It is generally advised to avoid the use of IRQ priority 7 when the CPU is in native mode. Alternatively, IRQ priority 7 may be rerouted to NMI.

## IRQ Priority 7 to NMI Option

A jumper on the CPU Shim allows IRQ7 to trigger an NMI instead of participating in Vector Pull Rewrite.
This is intended to support devices such as the RESTORE key on the C64, which expects to be able to
assert NMIB. Another motivation is to provide a useful alternative to the default effect of asserting
IRQ7 within the rewrite scheme, which is to force the pull of the RESET vector.

## Effect of Vector Pull Rewrite in Emulation (65C02) Mode
The 6502's IRQ vector, like its 65816 counterpart, has 0x111x in the last nybble, so it is detected by the Vector Pull Rewrite Shim. 

```
Emulation Mode Interrupt Vector Table  (datasheet)

$FFFA NMI
$FFFC RESB
$FFFE BRK/IRQ 
```

Unlike the 65816's IRQ vector, the 6502 IRQ vector occurs at the very top of its page, so additions of 1-7 to the bits may force A4 to overflow to 0 (no carry). In particular, $FFFE + $02 = $FFE0, etc. This means the augmented
IRQ vector map for the 6502 looks like this:

```
Emulation Mode Interrupt Vector Table (with IRQ0-7)

$FFE0 BRK/IRQ 1
$FFE2 BRK/IRQ 2
$FFE4 BRK/IRQ 3
$FFE6 BRK/IRQ 4
$FFE8 BRK/IRQ 5
$FFEA BRK/IRQ 6
$FFEC BRK/IRQ 7
...
$FFFA NMI
$FFFC RESB
$FFFE BRK/IRQ 0
```

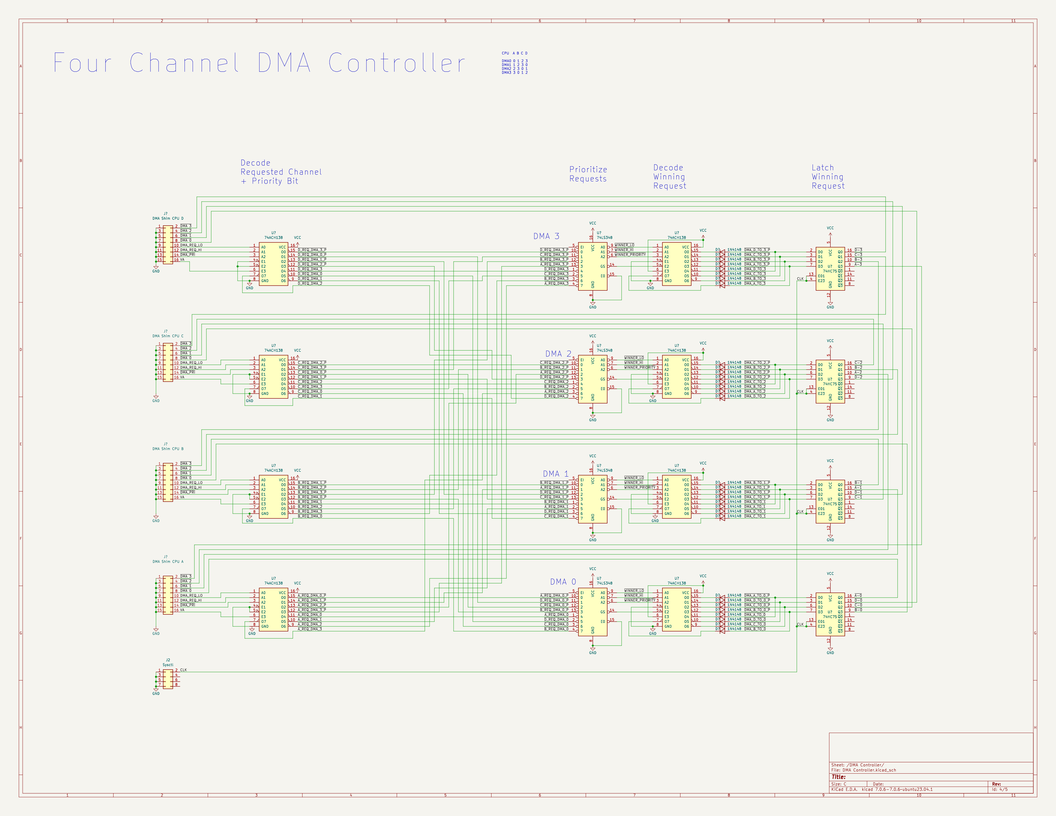
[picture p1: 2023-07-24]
kicad/Vega816/schematics/-DMA Controller.png

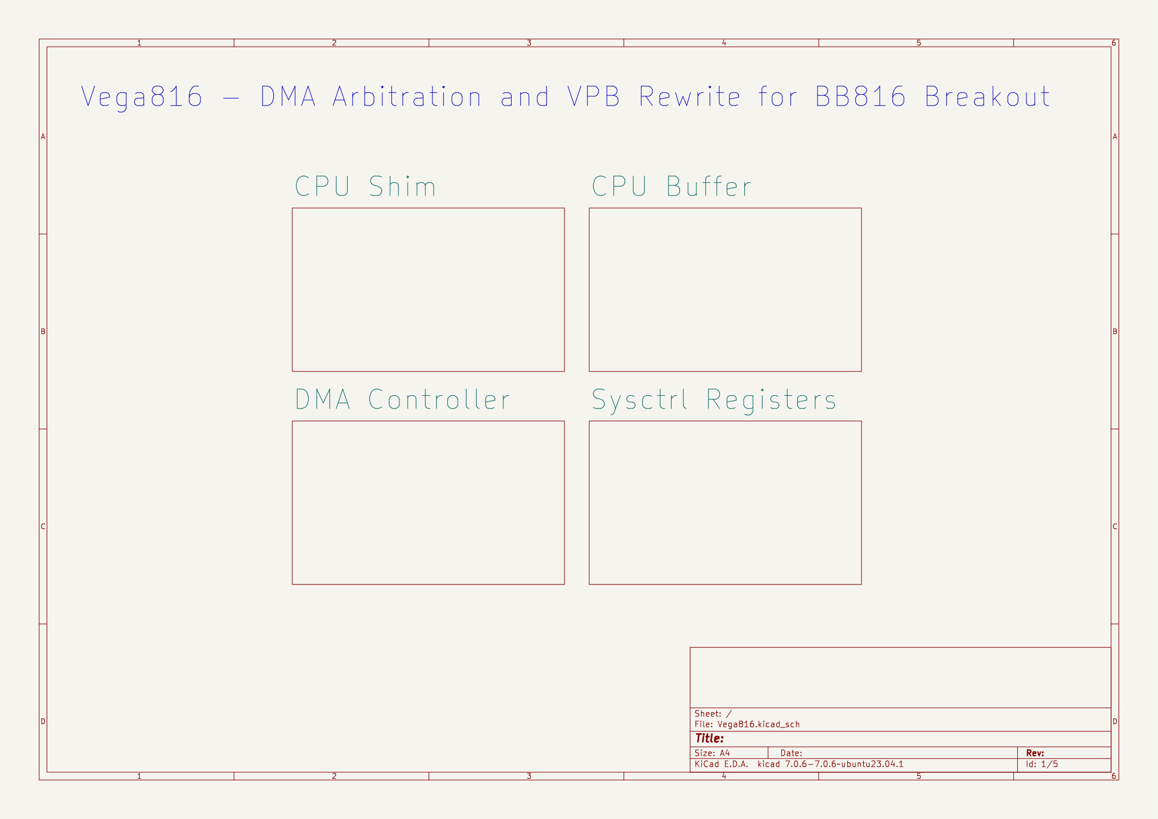
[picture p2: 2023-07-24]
kicad/Vega816/schematics/Schematic.png

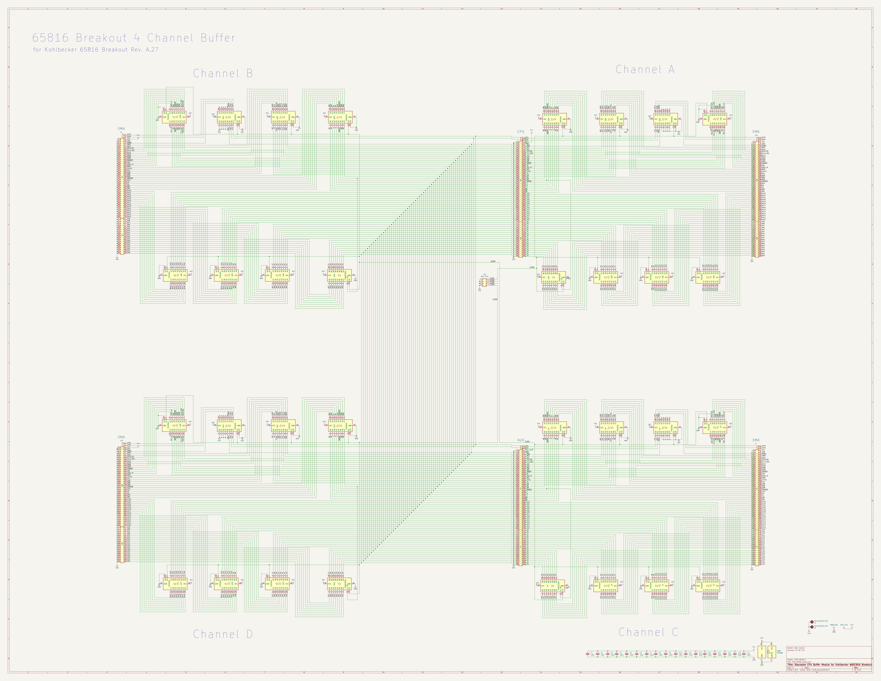
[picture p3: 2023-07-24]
kicad/Vega816/schematics/-CPU Buffer.png

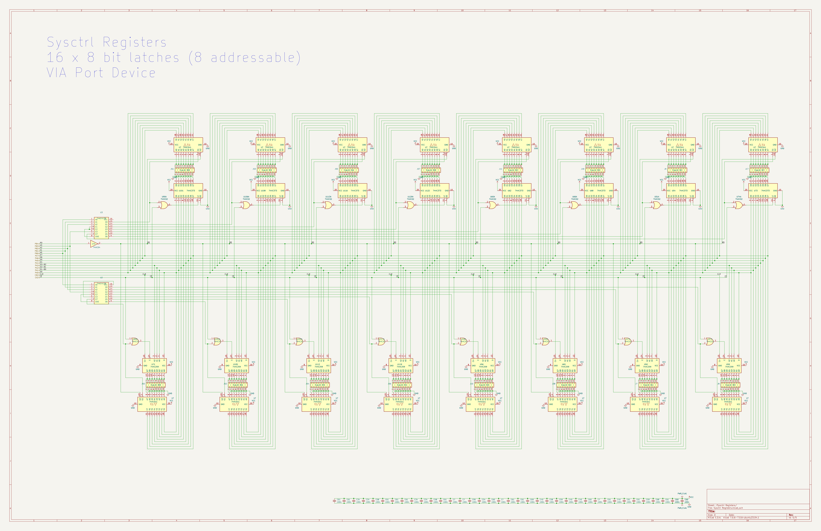
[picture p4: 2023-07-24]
kicad/Vega816/schematics/-Sysctrl Registers.png

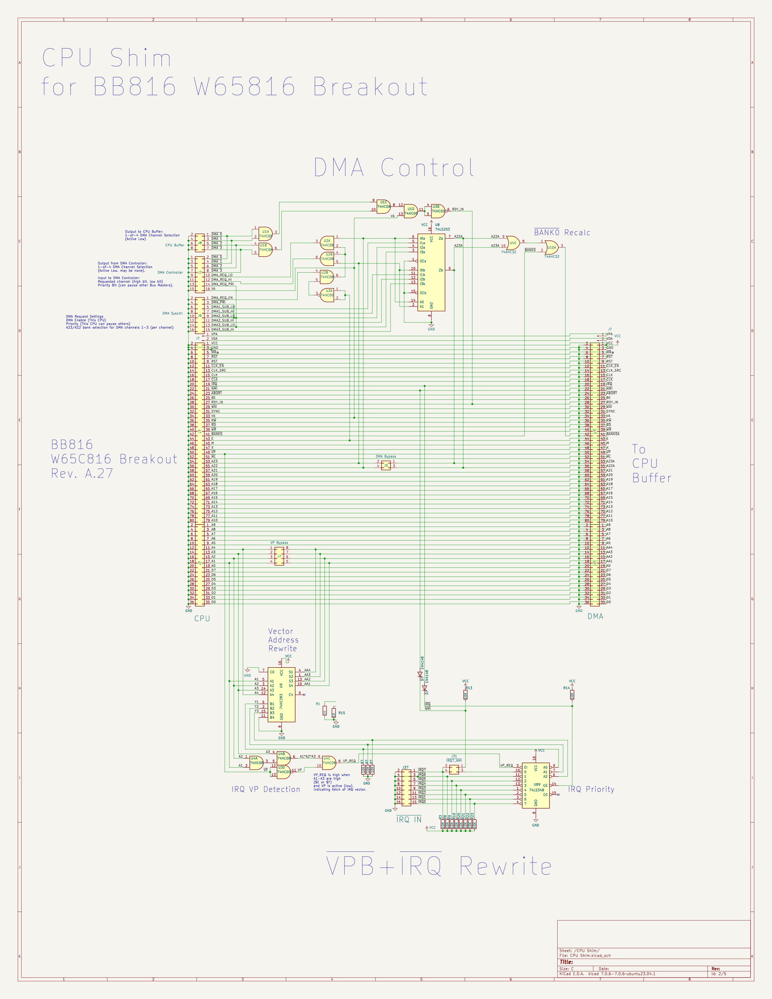
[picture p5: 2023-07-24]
kicad/Vega816/schematics/-CPU Shim.png

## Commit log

2023-06-01 Upload Kicad
    [16MB_Expansion_Bus.kicad_sch, 4MB_Memory_Module.kicad_sch, 64_to_32_16_8_byte_device_breakout.kicad_sch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]
2023-06-05 Update CPU Buffer
    [CPU Buffer.kicad_pcb, CPU Buffer.kicad_sch, Vega816.kicad_sch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]
2023-06-05 irq demultiplexer
    [EightToOneIRQMultiplexer.kicad_sch, Vega816.kicad_sch]
2023-06-05 expansion bus breakout
    [16MB_Expansion_Bus.kicad_sch, Vega816.kicad_sch]
2023-06-05 system controller
    [ACIA.kicad_sch, EightToOneIRQMultiplexer.kicad_sch, SystemController.kicad_sch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]
2023-06-06 via port rework
    [SystemController.kicad_sch, VIADevices.kicad_sch, VIAPort.kicad_sch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]
2023-06-10 irq shim
    [DMABreakout.kicad_sch, IRQDispatch.kicad_sch, Vega816.kicad_sch]
2023-06-11 expansion port hi ram
    [C64VIA2.kicad_sch, SystemController.kicad_sch, Vega816.kicad_sch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]
2023-06-12 new plots
    [16MB_Expansion_Bus.kicad_sch, 64_to_32_16_8_byte_device_breakout.kicad_sch, 6510.kicad_sch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]
2023-06-18 git ignor
    [Vega816.kicad_sch]
2023-07-01 Big push, Sysctl, DMA Reg
    [16MB_Expansion_Bus.kicad_sch, 4MB_Memory_Module.kicad_sch, 64_to_32_16_8_byte_device_breakout.kicad_sch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]
2023-07-24 Big ol update
    [16MB_Expansion_Bus.kicad_sch, ACIA.kicad_sch, C64 Hardware.kicad_sch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]
